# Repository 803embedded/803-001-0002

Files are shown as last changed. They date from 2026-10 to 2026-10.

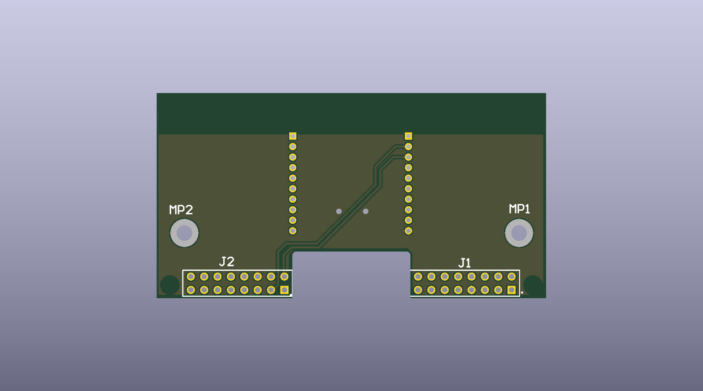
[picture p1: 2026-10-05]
803-001-002-A-bottom.png

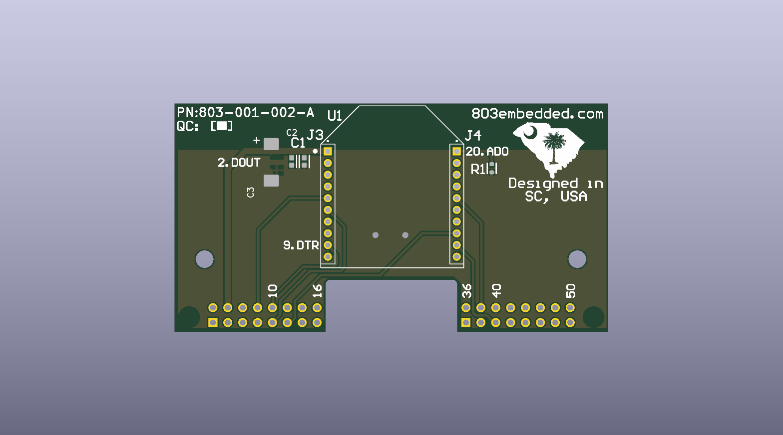
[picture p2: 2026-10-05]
803-001-002-A-top.png

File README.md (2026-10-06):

# 803-001-002-A - Digi cellular radio adapter for Toradex Viola

This KiCad 9 project is a native reconstruction of **803-001-001-B** from its released ODB++ manufacturing data. Connector and mounting-hole locations, board outline, signal routing, ground copper, and artwork are carried over from Rev B.

## Cellular modification

The original C3 10 uF / 1206 capacitor is replaced by:

- **C3: 220 uF, 16 V, polymer tantalum, 7343-31**
- KEMET `T521D227M016ATE025` (25 mΩ ESR)
- Digi-Key `399-T521D227M016ATE025CT-ND`

C3 is polarized; pad 1 / the marked end is VCC. Its center is shifted 0.94 mm left from the old C3 center to clear C2, and both pads have short 1.2 mm-wide connections into the unchanged VCC/GND copper.

TODO: update the below info

Digi's XBee Cellular 3G Global guide recommends at least 220 uF of bulk capacitance at VCC because cellular startup/wakeup inrush can approach 2 A. The existing 47 pF and 1 uF high-frequency bypass capacitors are retained. Reference:
<https://docs.digi.com/resources/documentation/digidocs/90001541/reference/r_cell_power_supply.htm>

## Validation notes

The schematic passes KiCad ERC with zero violations. Board DRC has zero errors. It retains warnings associated with the source reconstruction: legacy vector silkscreen contacts, custom footprints that intentionally differ from current KiCad library copies, and isolated same-net shapes carried over from ODB++. There are no unconnected items. The C3 area has no clearance, crossing, short-circuit, or unconnected-item violation. The WA-SMST spacer's intentional NPTH-in-copper construction is handled by two reference-scoped custom rules in `803-001-002-A.kicad_dru`.

## Project files

- `803-001-002-A.kicad_pro` - KiCad project
- `803-001-002-A.kicad_sch` - schematic
- `803-001-002-A.kicad_pcb` - two-layer PCB
- `803-001-002-A_BOM.csv` - assembly BOM

The XBee module itself is user-installed and is not part of the assembly BOM.

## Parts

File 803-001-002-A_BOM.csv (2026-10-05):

Reference | Qty | Value / Part | Manufacturer | MPN | Supplier | Supplier PN | Notes
C1 | 1 | 47pF 50V C0G 0603 | KEMET | C0603C470J5GACTU | Digi-Key | 399-C0603C470J5GACTUCT-ND | Retained from Rev B
C2 | 1 | 1uF 25V X7R 0603 | Murata Electronics | GCM188R71E105KA64J | Digi-Key | 490-GCM188R71E105KA64JCT-ND | Retained from Rev B
C3 | 1 | 220uF 16V polymer 7343-31 | KEMET | T521D227M016ATE025 | Digi-Key | 399-T521D227M016ATE025CT-ND | Cellular bulk bypass; polarized
R1 | 1 | 10k 1% 0603 | YAGEO | RC0603FR-0710KL | Digi-Key | 311-10.0KHRCT-ND | AD0 pull-down
J1,J2 | 2 | SSQ-108-03-G-D | Samtec Inc. | SSQ-108-03-G-D | Digi-Key | SAM1196-08-ND | Viola sockets, underside
J3,J4 | 2 | M22-7131042 | Harwin Inc. | M22-7131042 | Digi-Key | 952-1354-5-ND | XBee sockets
MP1,MP2 | 2 | WA-SMST 2.25mm H7 | Würth Elektronik | 9774070943R | Digi-Key | 732-10945-1-ND | SMT steel spacers, underside

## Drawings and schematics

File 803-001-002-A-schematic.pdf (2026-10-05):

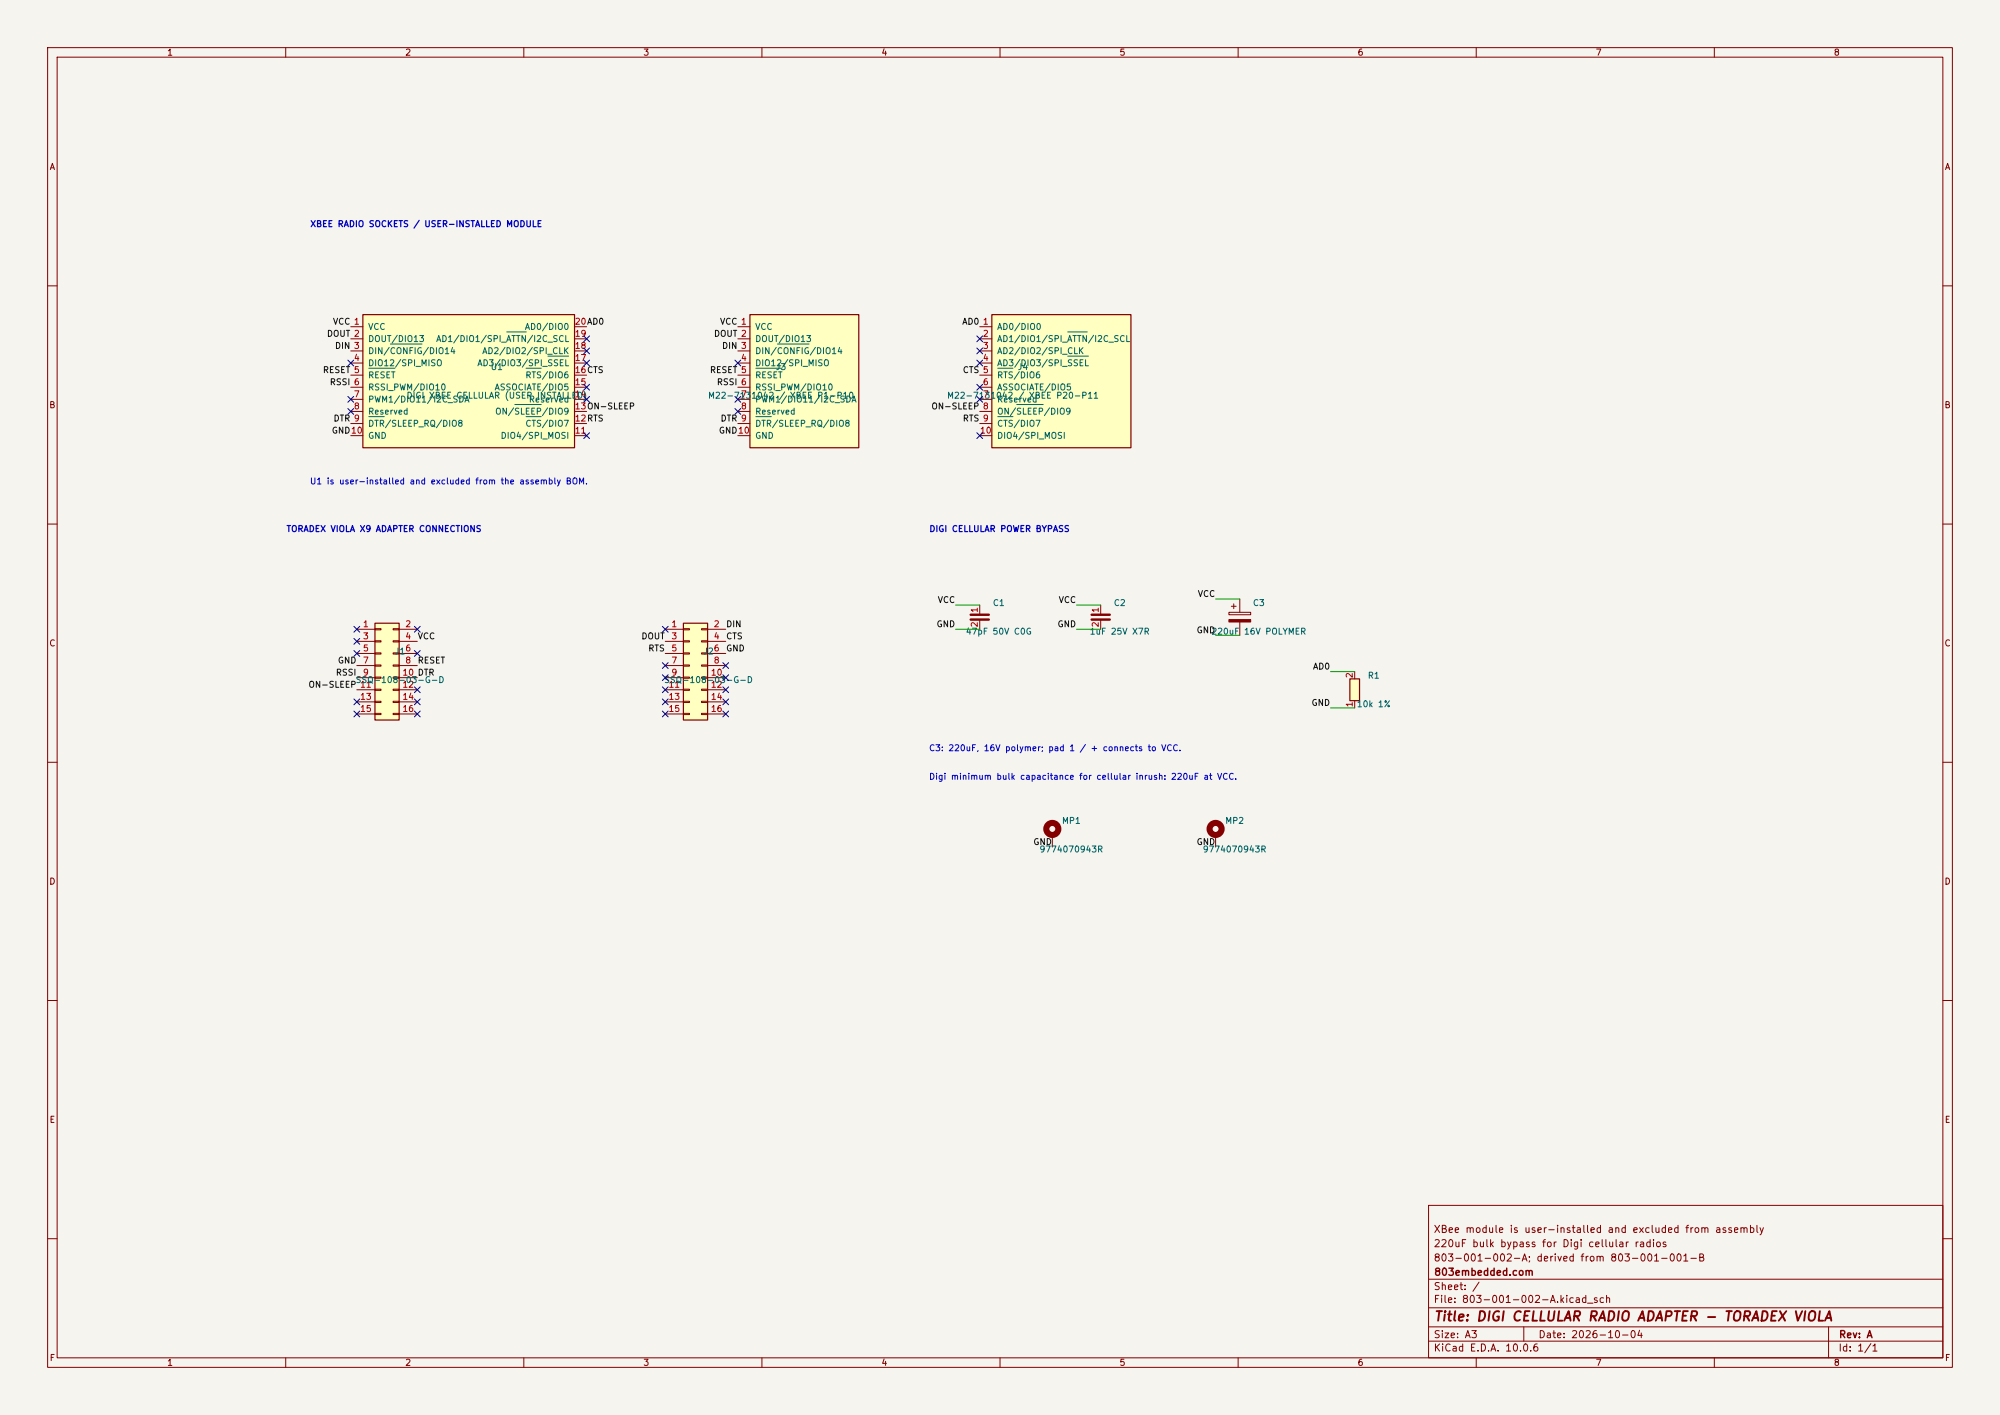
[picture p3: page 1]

XBEE RADIO SOCKETS / USER-INSTALLED MODULE

XBee module is user-installed and excluded from assembly
220uF bulk bypass for Digi cellular radios
803-001-002-A; derived from 803-001-001-B
803embedded.com
Sheet: /
File: 803-001-002-A.kicad_sch
Title: DIGI CELLULAR RADIO ADAPTER - TORADEX VIOLA

Size: A3 | Rev: A | F Date: 2026-10-04
KiCad E.D.A. 10.0.6 | Id: 1/1

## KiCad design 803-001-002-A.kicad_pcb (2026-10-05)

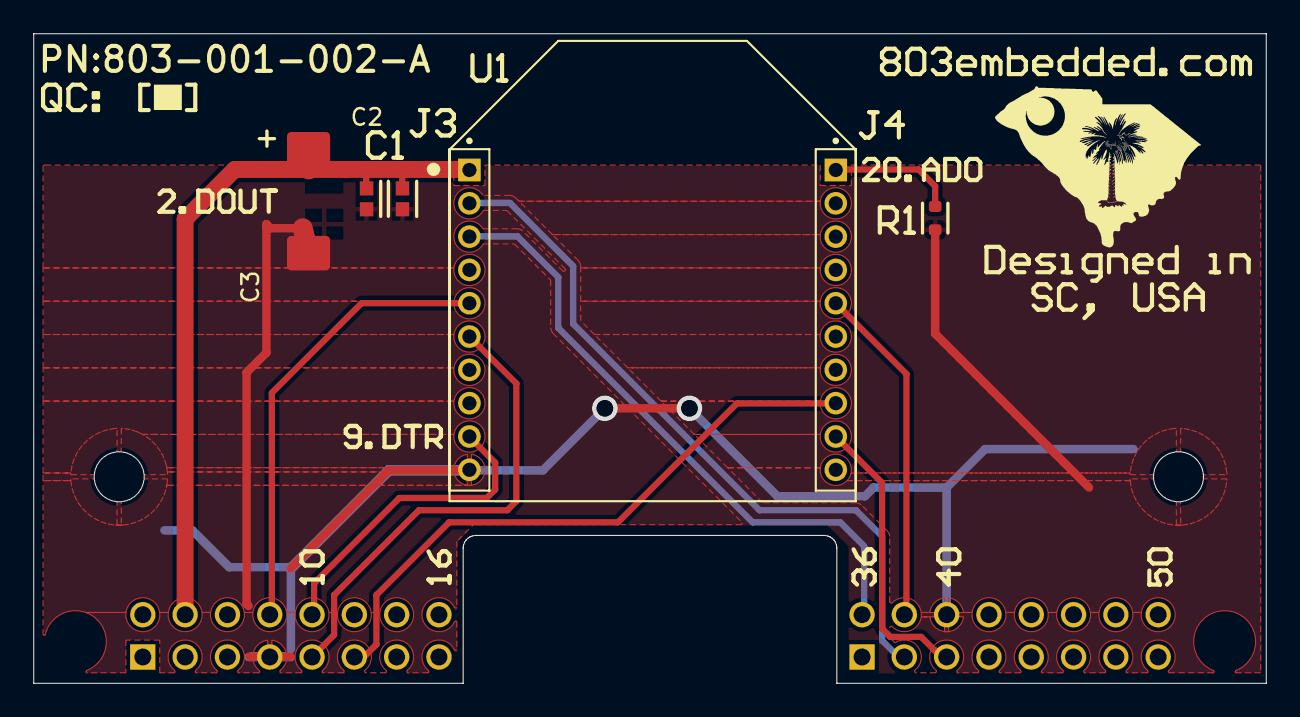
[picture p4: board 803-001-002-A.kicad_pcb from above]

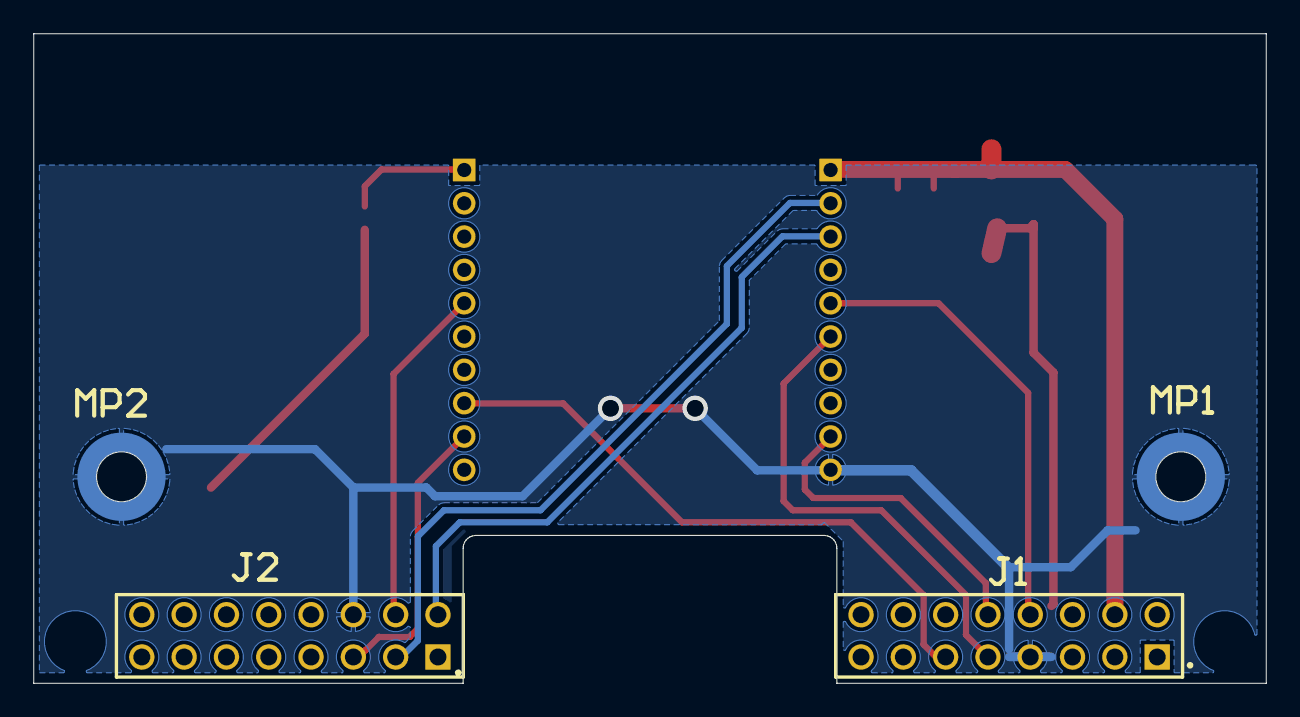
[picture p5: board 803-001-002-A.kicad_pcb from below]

Board: 2 copper layers, 74.0 x 39.0 mm, 10 parts (4 on the bottom side), 11 nets.

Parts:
C1: 47pF; C_0603_1608Metric
C2: 1uF; C_0603_1608Metric
C3: 220uF 16V; CP_EIA-7343-31_Kemet-D
J1, J2: SSQ-108-03-G-D; PinSocket_2x08_P2.54mm_Vertical
J3, J4: M22-7131042; PinSocket_1x10_P2.00mm_Vertical
MP1, MP2: 9774070943R; Mounting_Wuerth_WA-SMST-2.25mm_H7mm_9774070943
R1: 10k; R_0603_1608Metric

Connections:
AD0: J4.1, R1.2
CTS: J2.04, J4.5
DIN: J2.02, J3.3
DOUT: J2.03, J3.2
DTR: J1.10, J3.9
GND: C1.2, C2.2, C3.2, J1.07, J2.06, J3.10, MP1.1, MP2.1, R1.1
ON-SLEEP: J1.11, J4.8
RESET: J1.08, J3.5
RSSI: J1.09, J3.6
RTS: J2.05, J4.9
VCC: C1.1, C2.1, C3.1, J1.04, J3.1

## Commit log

2026-10-05 Initial commit of 803-001-0002
    [803-001-002-A.kicad_pcb, 803-001-002-A.kicad_sch, 803-001-002-A_BOM.csv]
2026-10-05 Opened in KiCAD v10
    [803-001-002-A.kicad_pcb]
